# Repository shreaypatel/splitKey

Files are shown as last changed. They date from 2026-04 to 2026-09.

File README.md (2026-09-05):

# Ataraxia - Custom 50% Split Keyboard

### Description
Ataraxia is a wireless 52-key, 3D printed ergonomic keyboard desinged for a focused typing experience. The board is powered by dual Seeed Studio XIAO nRF52840 microcontrollers running ZMK firmware. 
It utilizes Bluetooth 5.0 to communicate seamlessly without a cable connecting the halves. The hardware stack includes a custom-routed printed circuit board, Kailh MX hotswap sockets, and direct-wired 
350mAh LiPo batteries for extended operational life.

This project was designed to create an open source, minimalist workspace that promotes ergonomic health withouting compromising functionality. Beyond the physical utility, it serves as a 
comprehensive hardware engineering exercise. Building this keyboard helped me learn engineering design, CAD modeling, PCB routing, soldering, and embedded firmware compilation. Check out the web app to learn touch typing on this split keyboard layout here: https://ataraxiatype.netlify.app/



3D Model
angle33CAD
angle2CAD
*Full mechanical assembly modeled in Onshape.*

Custom PCB
3dviewbacksdie5
3dviewfrontside
pcbEditorCompleteWiring
*Custom PCB designed and routed in KiCad.*

Wiring Diagram

batteryWiringDiagram
*Simplified direct-wiring diagram connecting the 3.7V LiPo battery to the XIAO nRF52840.*

Bill of Materials (BOM)
[Click here to view the full Bill of Materials (CSV)](<BOM/splitkeyBOM - Sheet1.csv>)

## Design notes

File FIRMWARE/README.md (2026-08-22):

# Firmware (mirror)

This folder mirrors the keyboard definition used to **build** ZMK firmware.

| Repo | Role |
|---|---|
| [zmk-config-ataraxia](https://github.com/shreaypatel/zmk-config-ataraxia) | Source of truth for GitHub Actions builds / flashing |
| `FIRMWARE/` in this repo | Same shield, keymap, and config files for documentation and review |

Keep these in sync when you change pins, matrix transform, or key bindings. Prefer editing [zmk-config-ataraxia](https://github.com/shreaypatel/zmk-config-ataraxia) first, then copy the matching paths here.

### Layout

```
FIRMWARE/
  build.yaml
  config/
    ataraxia.conf
    ataraxia.keymap
    west.yml
    boards/shields/ataraxia/
      ataraxia.dtsi
      ataraxia_left.overlay
      ataraxia_right.overlay
      Kconfig.defconfig
      Kconfig.shield
      ataraxia.zmk.yml
  zephyr/
    module.yml
```

ZMK does not use a project `main.c` for this board — hardware and keymap live in the DeviceTree overlays / `.dtsi` and `.keymap` files above.

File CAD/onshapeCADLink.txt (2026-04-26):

https://cad.onshape.com/documents/b6f8556d38045e68e5a1e84c/w/d274bab0f518b6b404911204/e/6b84c119cb265b001b29e227

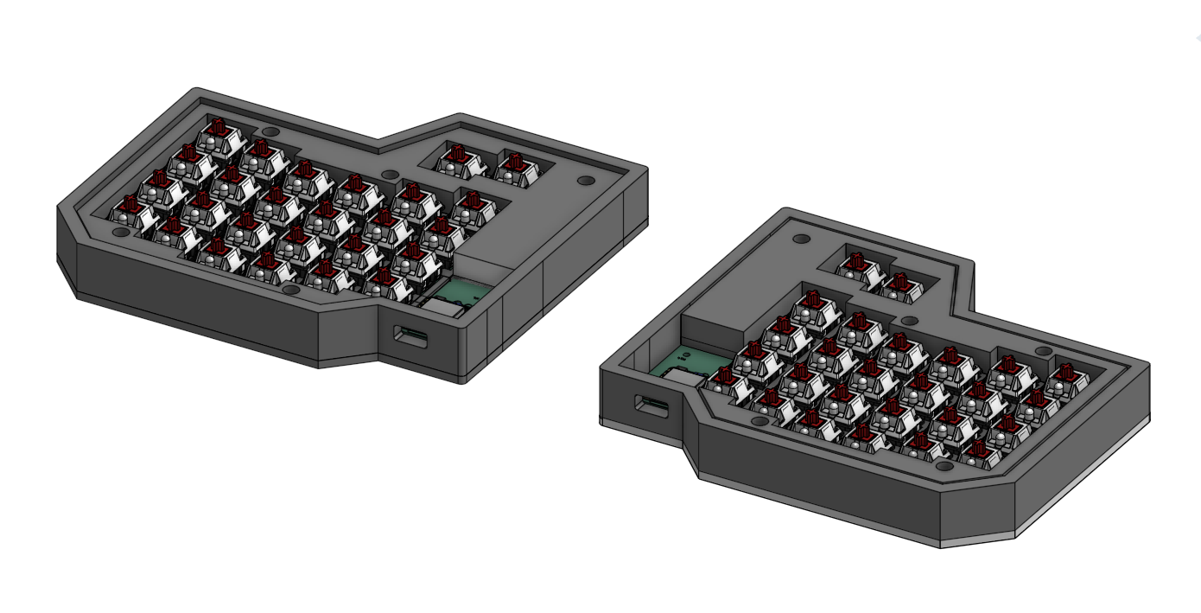
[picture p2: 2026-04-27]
CAD/angle2CAD.png

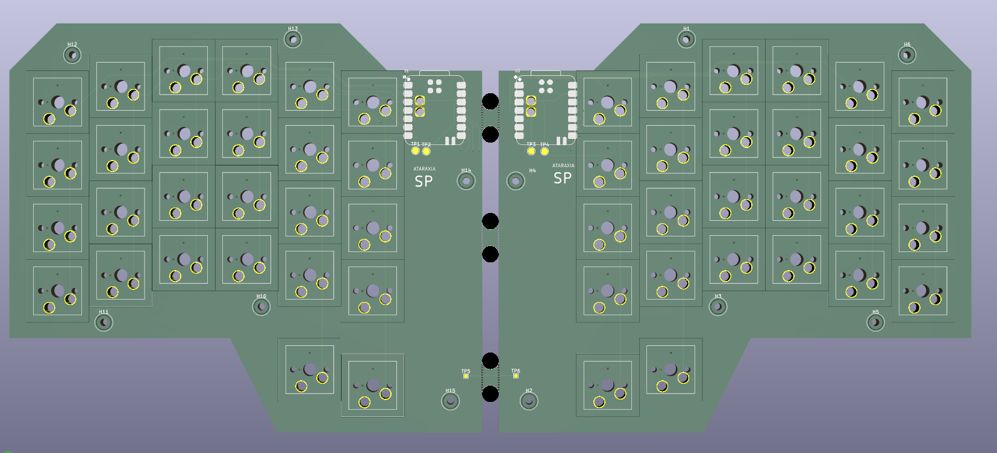
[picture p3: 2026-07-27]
PCB/3dviewfrontside.png

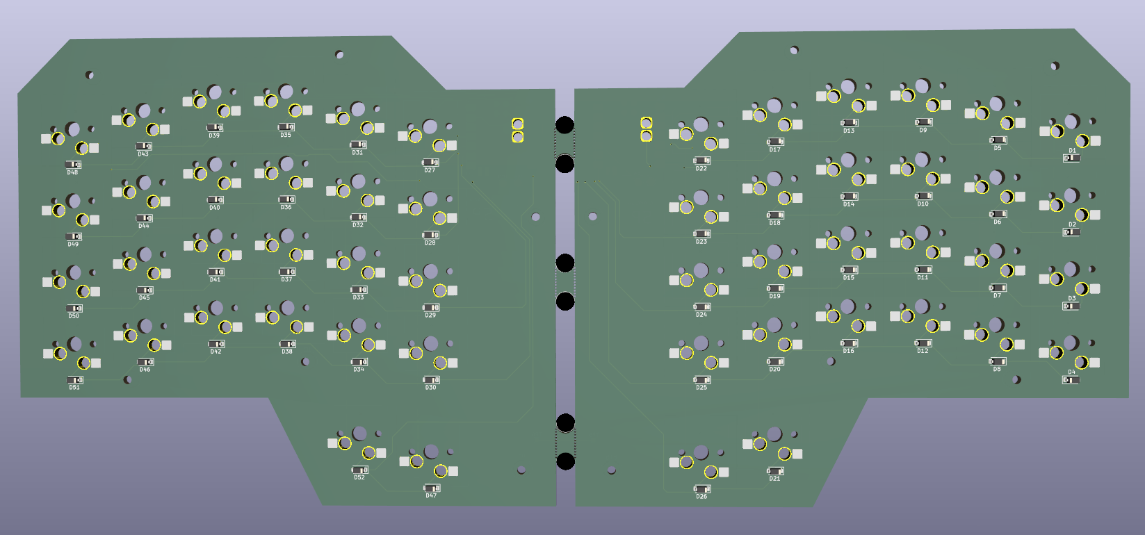
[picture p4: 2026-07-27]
PCB/3dviewbacksdie5.png

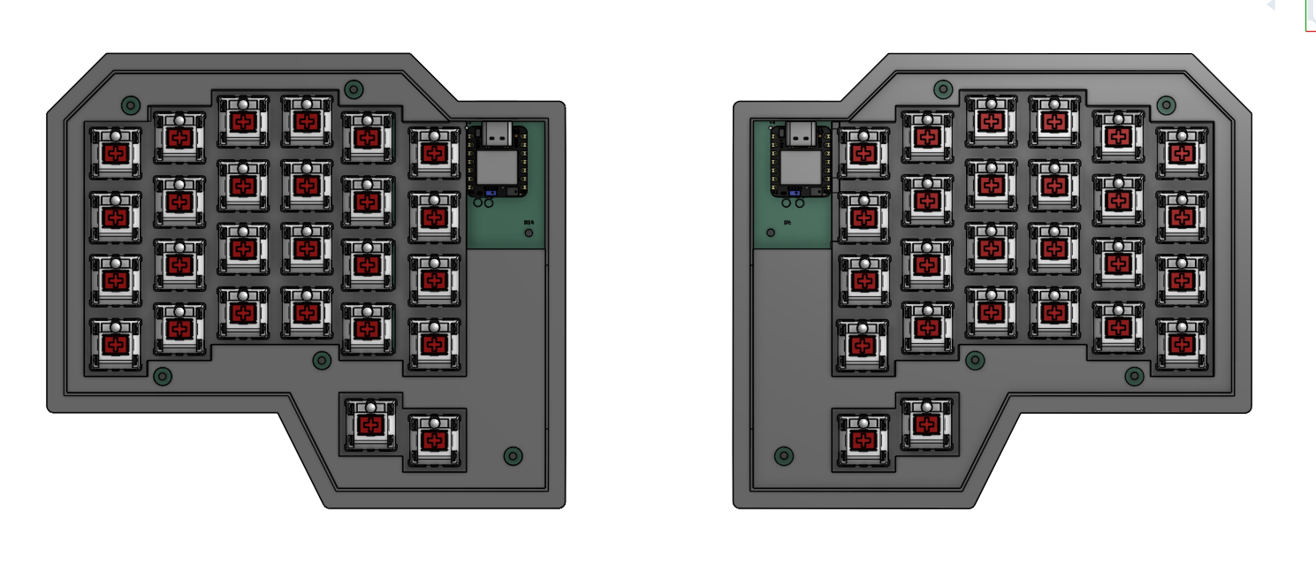
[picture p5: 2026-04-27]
CAD/angle3CAD.png

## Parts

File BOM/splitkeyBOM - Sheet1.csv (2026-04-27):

Part | Price (USD) | Quantity | Total Cost Inlcuding Shipping(USD) | Website
Lipo Battery 3.7 V | 4.95 | 2 | 8.12 | https://www.aliexpress.com/item/33007984508.html?src=google
PCB | 18.5 | 5 | 28.04 | https://cart.jlcpcb.com/shopcart/cart/
MX Switches | 0.09875 | 80 | 7.90 | https://www.aliexpress.com/item/1005011838889689.html?scm_id=1007.40050.354490.0&scm-url=1007.40050.354490.0
PBT Keycaps | 0.2572 | 25 | 6.43 | https://www.aliexpress.com/item/32842379355.html?mp=1
XIAO nRF52840 | 10.69 | 2 | 21.38 | https://www.aliexpress.com/item/1005006988954136.html?scm_id=1007.13440.426876.0&scm-url=1007.13440.426876.0
1N5819 Diodes | 0.0322 | 100 | 3.22 | https://www.aliexpress.com/item/1005010373909049.html?curPageLogUid=VT8pOmptmrYM
Hot-Swap PCB Socket | 0.09542857143 | 70 | 6.68 | https://www.aliexpress.com/item/1005007225352311.html?scm_id=1007.40050.354490.0&scm-url=1007.40050.354490.0
M2 threaded brass inserts | 0.0458 | 50 | 2.29 | https://www.aliexpress.com/item/1005008666672949.html?curPageLogUid=kukGMW7BGeht
M2 Screws 4mm length | 0.0286 | 50 | 1.43 | https://www.aliexpress.com/item/32967225441.html?curPageLogUid=wkBiljUuE5jX
3D printed case |  | 1 | 0.00 | printing at home
 |  |  | 85.49

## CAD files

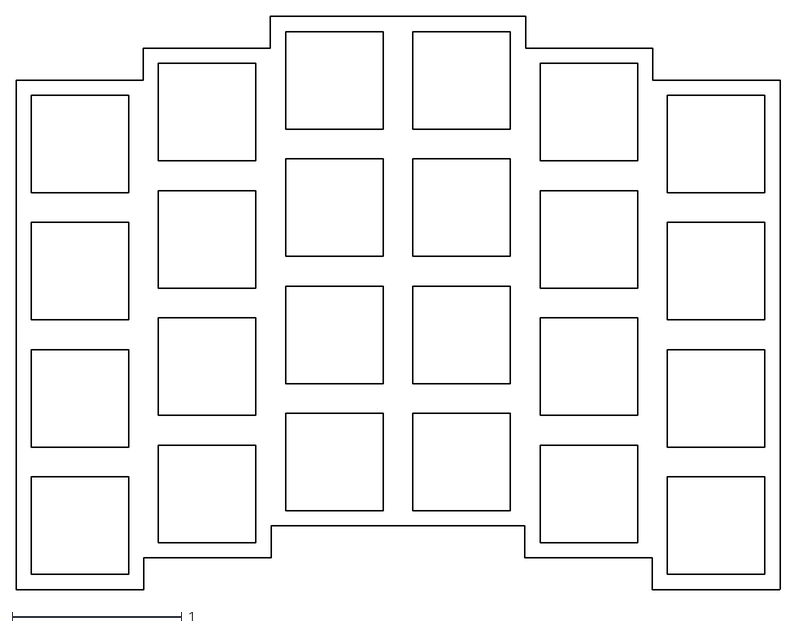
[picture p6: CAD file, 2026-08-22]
web/rightkeyoutlinemain.dxf
4.50 x 3.38

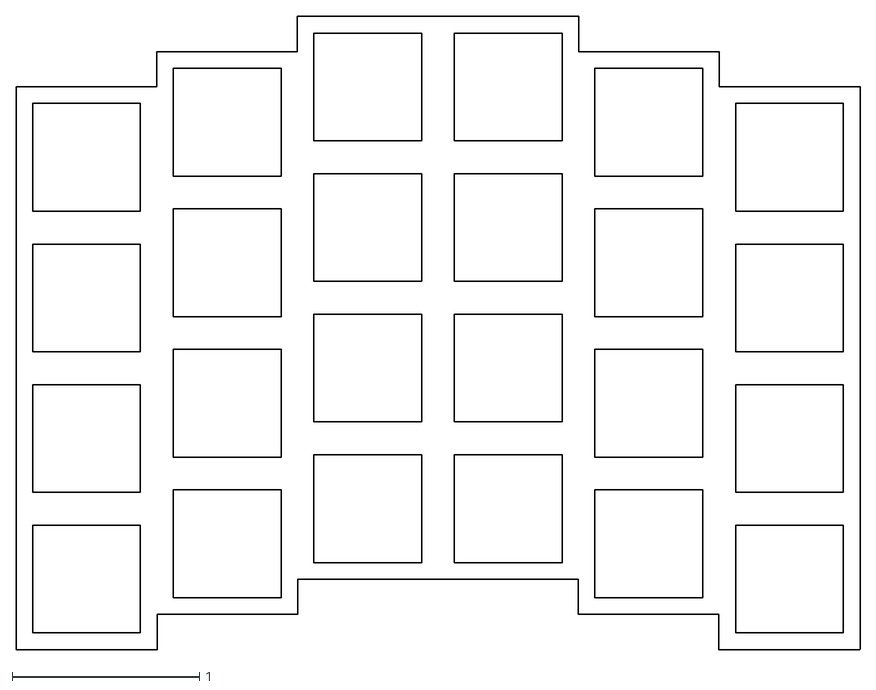
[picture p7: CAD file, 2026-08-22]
web/leftKeyOutlineMain.dxf
4.50 x 3.38

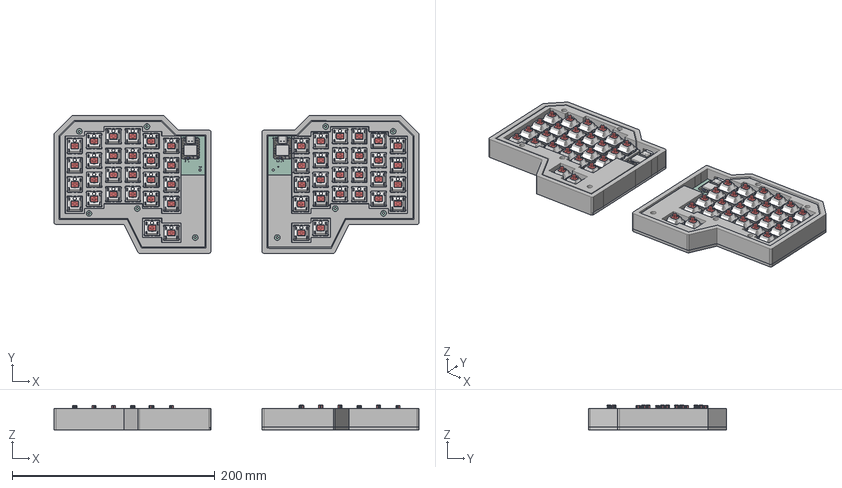
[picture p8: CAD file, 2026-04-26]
CAD/splitKeyElectronics.step
360.1 x 135.9 x 24.6 mm
splitKey_silkscreen x 249
Pieza5^Cherry MX x 52
Pulsador x 52
Pin1 x 52
Led 3mm_trans x 104
BOSS-EXTRUDE14_10_ x 2
PCB (1) x 32
CAP 3 x 6
Pin2 x 52
Bottom x 52
BOSS-EXTRUDE7_7_ x 2
Pins x 8
MIRROR2 x 2
Top x 52
MSM261D3526H1CPM x 16
LED x 8
BOSS-EXTRUDE14_12_ x 2
BOSS-EXTRUDE7_9_ x 2
Silkscreen x 26
CAP x 12
BOSS-EXTRUDE14_9_ x 2
ANT1 x 6
Surface 250
BOSS-EXTRUDE14_8_ x 2
BOSS-EXTRUDE7_4_ x 2
splitKey_PCB_2
BOSS-EXTRUDE14_2_ x 2
CUT-EXTRUDE5 x 2
Shield x 2
BOSS-EXTRUDE14_7_ x 2
BOSS-EXTRUDE7_2_ x 2
BOSS-EXTRUDE14_1_ x 2
BOSS-EXTRUDE14_11_ x 2
BOSS-EXTRUDE7_1_ x 2
BOSS-EXTRUDE14_5_ x 2
BOSS-EXTRUDE7_3_ x 2
BOSS-EXTRUDE14_6_ x 2
BOSS-EXTRUDE7_5_ x 2
BOSS-EXTRUDE7_8_ x 2
USR x 2
BOSS-EXTRUDE7_6_ x 2
splitKey_PCB_1
BOSS-EXTRUDE14_4_ x 2
BOSS-EXTRUDE14_3_ x 2

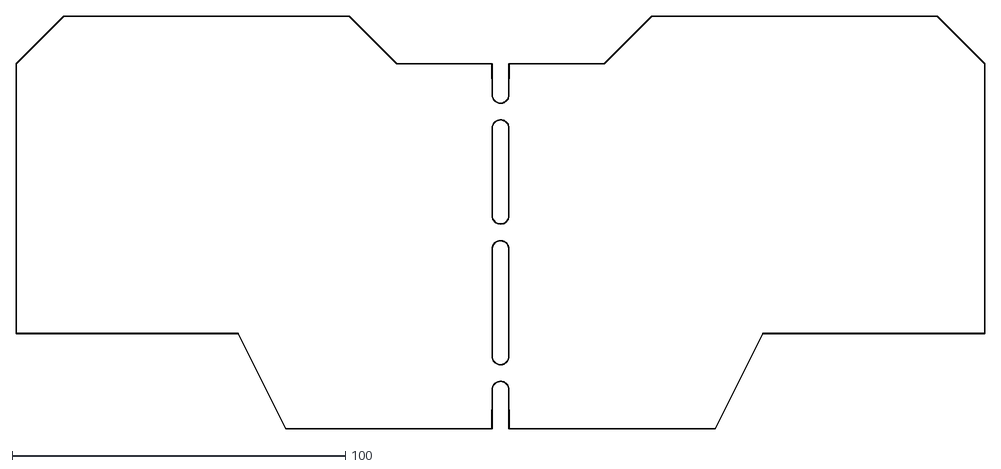
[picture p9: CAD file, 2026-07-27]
PCB/sourceFiles/splitKey-Edge_Cuts.dxf
290.9 x 123.9

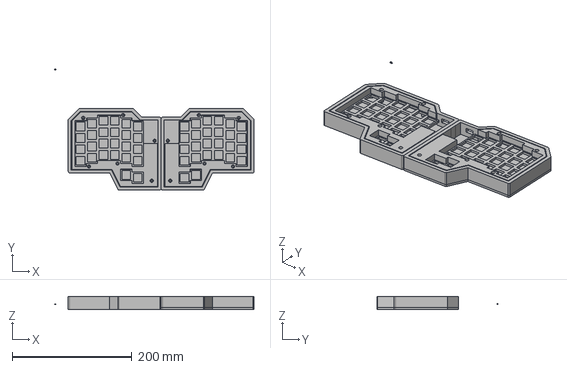
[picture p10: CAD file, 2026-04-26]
CAD/splitKeyCaseEnclosure.step
333.9 x 202.1 x 21.0 mm

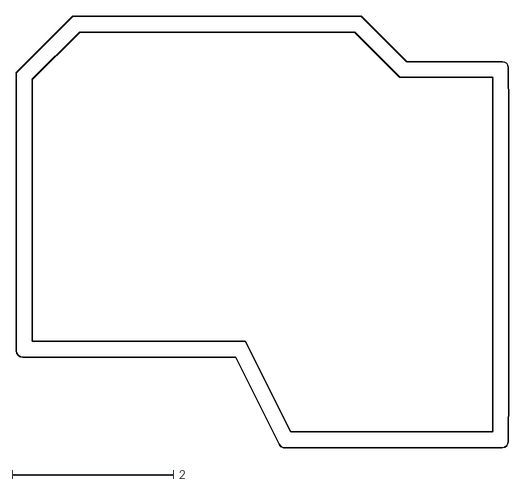
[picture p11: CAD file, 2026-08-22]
web/left outline.dxf
6.10 x 5.35

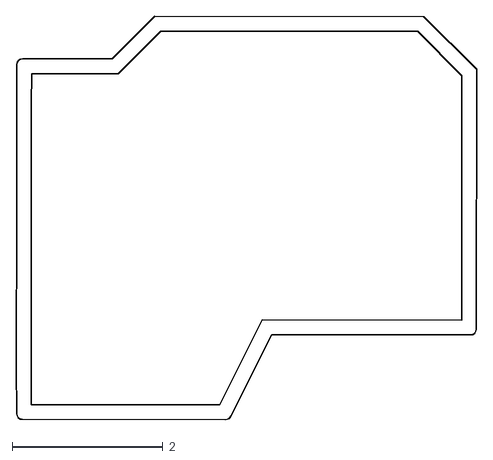
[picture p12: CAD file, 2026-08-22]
web/rightOUtline.dxf
6.10 x 5.35

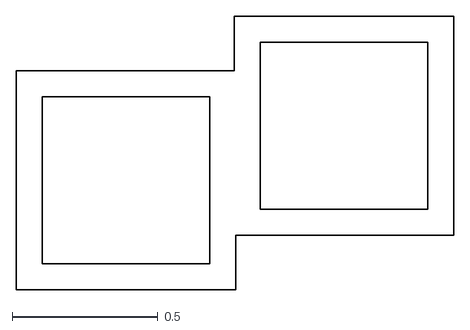
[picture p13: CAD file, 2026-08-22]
web/rightkeyoutlinethumbcluster.dxf
1.50 x 0.941

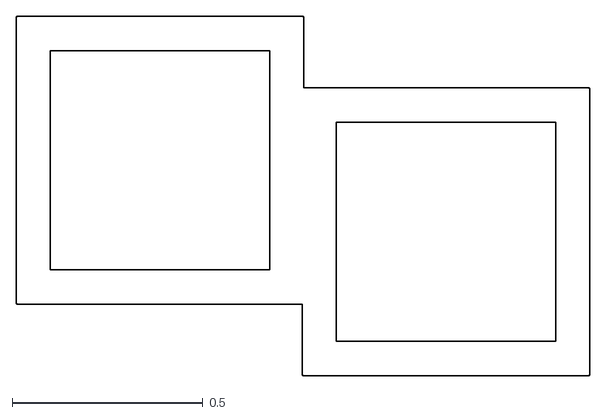
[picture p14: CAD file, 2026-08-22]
web/leftkeyOutlineThumbCluster.dxf
1.50 x 0.941

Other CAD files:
PCB/sourceFiles/splitKey-F_Silkscreen.dxf

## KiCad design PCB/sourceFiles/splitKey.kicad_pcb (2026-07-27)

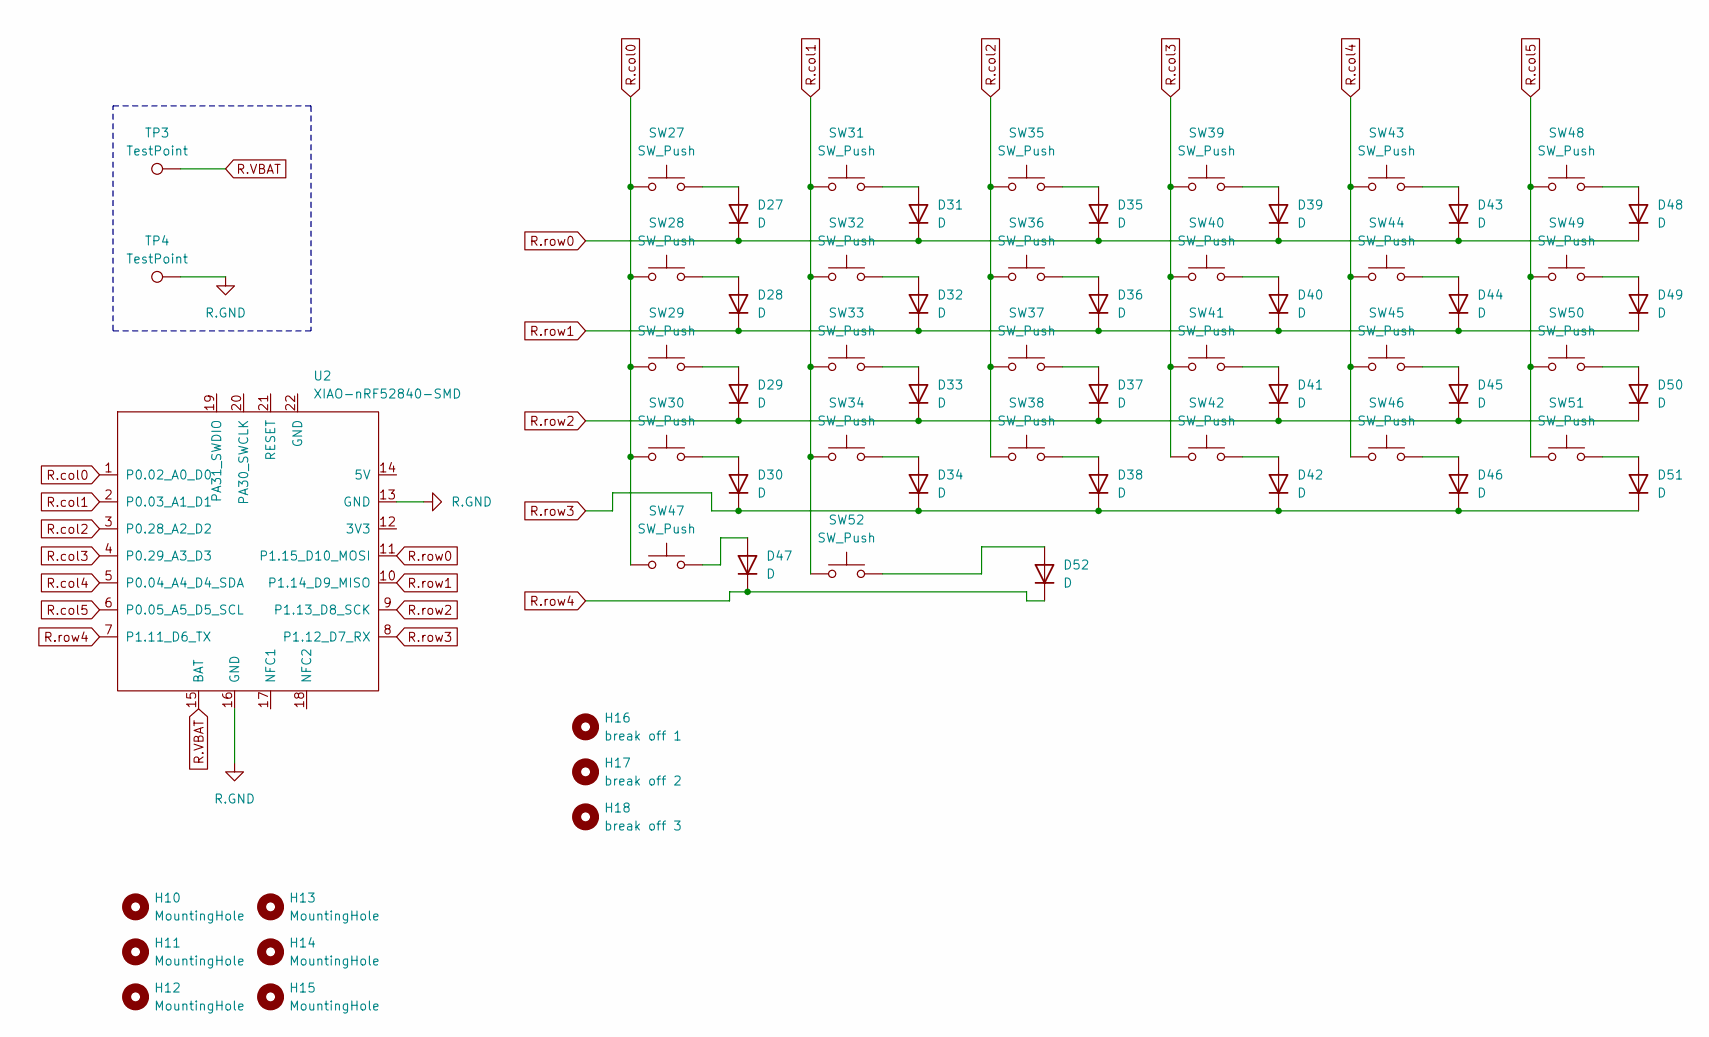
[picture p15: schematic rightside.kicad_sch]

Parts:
D27, D28, D29, D30, D31, D32, D33, D34, D35, D36, D37, D38, D39, D40, D41, D42, D43, D44, D45, D46, D47, D48, D49, D50, D51, D52: D; D_SOD-123
H10, H11, H12, H13, H14, H15: MountingHole; MountingHole_2.2mm_M2
H16: break off 1; mouse-bite-5mm-slot
H17: break off 2; mouse-bite-5mm-slot
H18: break off 3; mouse-bite-5mm-slot
SW27, SW28, SW29, SW30, SW31, SW32, SW33, SW34, SW35, SW36, SW37, SW38, SW39, SW40, SW41, SW42, SW43, SW44, SW45, SW46, SW47, SW48, SW49, SW50, SW51, SW52: SW_Push; MX_Hotswap_1.00u
TP3, TP4: TestPoint; TestPoint_Pad_D2.0mm
U2: XIAO-nRF52840-SMD; modified-XIAO-nRF52840-SMD

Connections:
unnamed: D27.2 (A), SW27.2
unnamed: D28.2 (A), SW28.2
unnamed: D29.2 (A), SW29.2
unnamed: D30.2 (A), SW30.2
unnamed: D31.2 (A), SW31.2
unnamed: D32.2 (A), SW32.2
unnamed: D33.2 (A), SW33.2
unnamed: D34.2 (A), SW34.2
unnamed: D35.2 (A), SW35.2
unnamed: D36.2 (A), SW36.2
unnamed: D37.2 (A), SW37.2
unnamed: D38.2 (A), SW38.2
unnamed: D39.2 (A), SW39.2
unnamed: D40.2 (A), SW40.2
unnamed: D41.2 (A), SW41.2
unnamed: D42.2 (A), SW42.2
unnamed: D43.2 (A), SW43.2
unnamed: D44.2 (A), SW44.2
unnamed: D45.2 (A), SW45.2
unnamed: D46.2 (A), SW46.2
unnamed: D47.2 (A), SW47.2
unnamed: D48.2 (A), SW48.2
unnamed: D49.2 (A), SW49.2
unnamed: D50.2 (A), SW50.2
unnamed: D51.2 (A), SW51.2
unnamed: D52.2 (A), SW52.2
R.GND: TP4.1 (1_1), U2.13 (GND), U2.16 (GND)
R.VBAT: TP3.1 (1_1), U2.15 (BAT)
R.col0: SW27.1, SW28.1, SW29.1, SW30.1, SW47.1, U2.1 (P0.02_A0_D0)
R.col1: SW31.1, SW32.1, SW33.1, SW34.1, SW52.1, U2.2 (P0.03_A1_D1)
R.col2: SW35.1, SW36.1, SW37.1, SW38.1, U2.3 (P0.28_A2_D2)
R.col3: SW39.1, SW40.1, SW41.1, SW42.1, U2.4 (P0.29_A3_D3)
R.col4: SW43.1, SW44.1, SW45.1, SW46.1, U2.5 (P0.04_A4_D4_SDA)
R.col5: SW48.1, SW49.1, SW50.1, SW51.1, U2.6 (P0.05_A5_D5_SCL)
R.row0: D27.1 (K), D31.1 (K), D35.1 (K), D39.1 (K), D43.1 (K), D48.1 (K), U2.11 (P1.15_D10_MOSI)
R.row1: D28.1 (K), D32.1 (K), D36.1 (K), D40.1 (K), D44.1 (K), D49.1 (K), U2.10 (P1.14_D9_MISO)
R.row2: D29.1 (K), D33.1 (K), D37.1 (K), D41.1 (K), D45.1 (K), D50.1 (K), U2.9 (P1.13_D8_SCK)
R.row3: D30.1 (K), D34.1 (K), D38.1 (K), D42.1 (K), D46.1 (K), D51.1 (K), U2.8 (P1.12_D7_RX)
R.row4: D47.1 (K), D52.1 (K), U2.7 (P1.11_D6_TX)

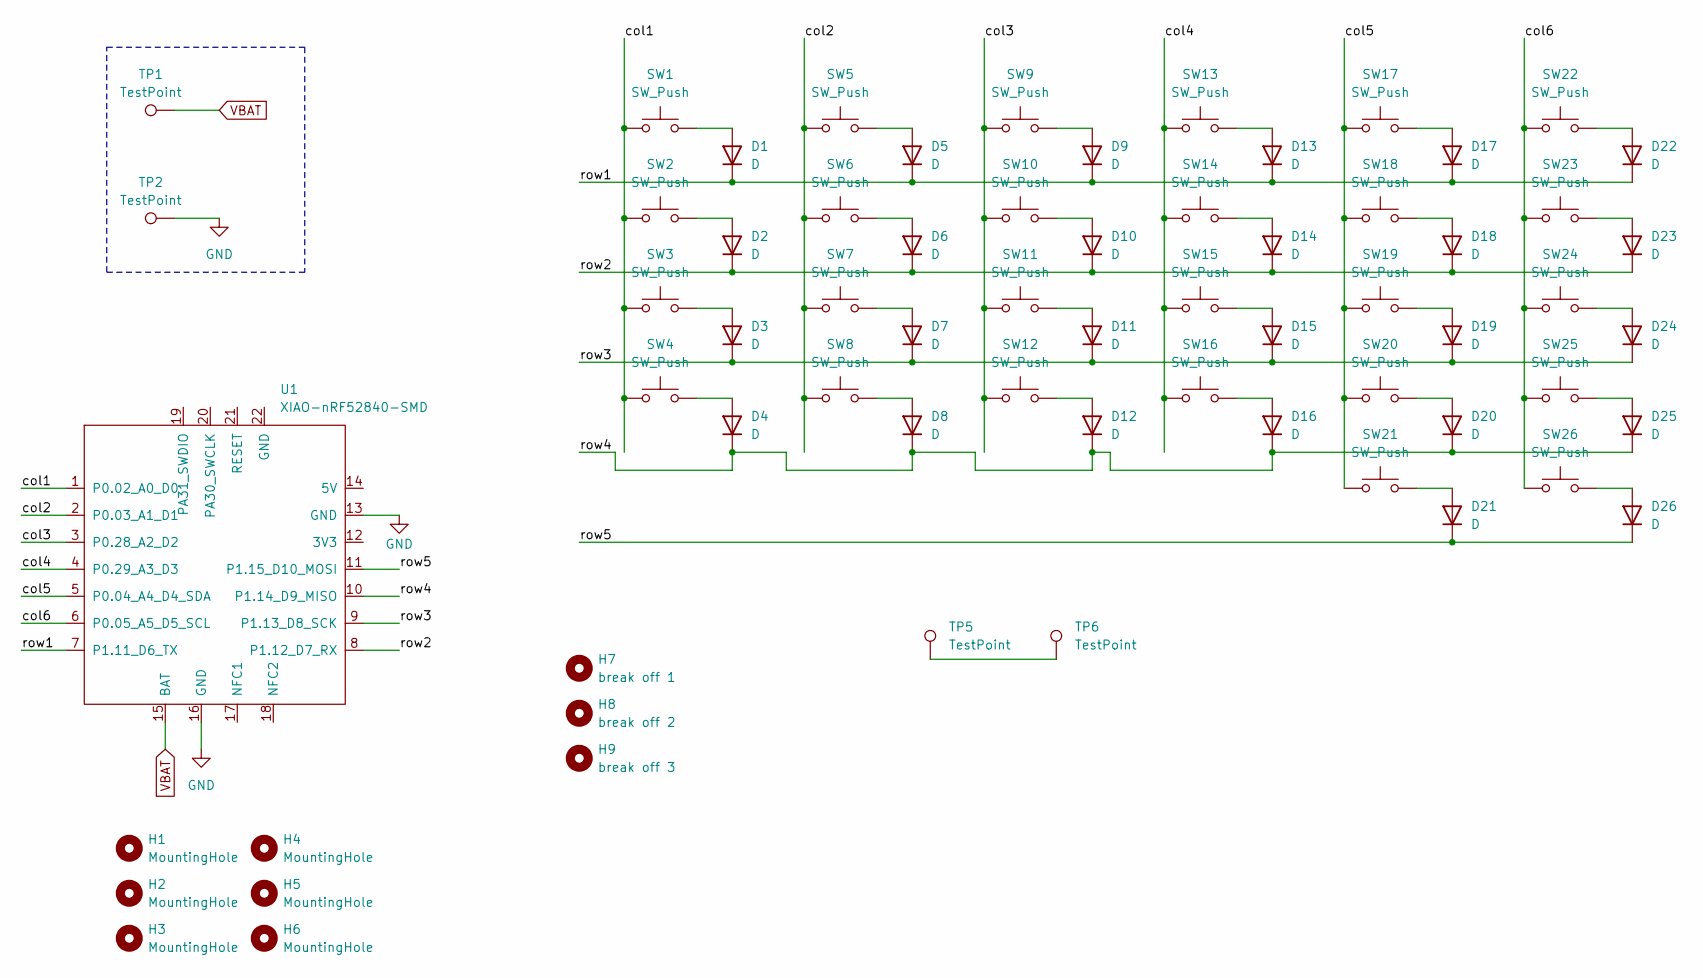
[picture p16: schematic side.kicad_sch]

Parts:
D1, D2, D3, D4, D5, D6, D7, D8, D9, D10, D11, D12, D13, D14, D15, D16, D17, D18, D19, D20, D21, D22, D23, D24, D25, D26: D; D_SOD-123
H1, H2, H3, H4, H5, H6: MountingHole; MountingHole_2.2mm_M2
H7: break off 1; mouse-bite-5mm-slot
H8: break off 2; mouse-bite-5mm-slot
H9: break off 3; mouse-bite-5mm-slot
SW1, SW2, SW3, SW4, SW5, SW6, SW7, SW8, SW9, SW10, SW11, SW12, SW13, SW14, SW15, SW16, SW17, SW18, SW19, SW20, SW21, SW22, SW23, SW24, SW25, SW26: SW_Push; MX_Hotswap_1.00u
TP1, TP2: TestPoint; TestPoint_Pad_D2.0mm
TP5, TP6: TestPoint; TestPoint_Pad_1.0x1.0mm
U1: XIAO-nRF52840-SMD; modified-XIAO-nRF52840-SMD

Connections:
/left/col1: SW1.1, SW2.1, SW3.1, SW4.1, U1.1 (P0.02_A0_D0)
/left/col2: SW5.1, SW6.1, SW7.1, SW8.1, U1.2 (P0.03_A1_D1)
/left/col3: SW9.1, SW10.1, SW11.1, SW12.1, U1.3 (P0.28_A2_D2)
/left/col4: SW13.1, SW14.1, SW15.1, SW16.1, U1.4 (P0.29_A3_D3)
/left/col5: SW17.1, SW18.1, SW19.1, SW20.1, SW21.1, U1.5 (P0.04_A4_D4_SDA)
/left/col6: SW22.1, SW23.1, SW24.1, SW25.1, SW26.1, U1.6 (P0.05_A5_D5_SCL)
/left/row1: D1.1 (K), D5.1 (K), D9.1 (K), D13.1 (K), D17.1 (K), D22.1 (K), U1.7 (P1.11_D6_TX)
/left/row2: D2.1 (K), D6.1 (K), D10.1 (K), D14.1 (K), D18.1 (K), D23.1 (K), U1.8 (P1.12_D7_RX)
/left/row3: D3.1 (K), D7.1 (K), D11.1 (K), D15.1 (K), D19.1 (K), D24.1 (K), U1.9 (P1.13_D8_SCK)
/left/row4: D4.1 (K), D8.1 (K), D12.1 (K), D16.1 (K), D20.1 (K), D25.1 (K), U1.10 (P1.14_D9_MISO)
/left/row5: D21.1 (K), D26.1 (K), U1.11 (P1.15_D10_MOSI)
GND: TP2.1 (1_1), U1.13 (GND), U1.16 (GND)
unnamed: D1.2 (A), SW1.2
unnamed: D2.2 (A), SW2.2
unnamed: D3.2 (A), SW3.2
unnamed: D4.2 (A), SW4.2
unnamed: D5.2 (A), SW5.2
unnamed: D6.2 (A), SW6.2
unnamed: D7.2 (A), SW7.2
unnamed: D8.2 (A), SW8.2
unnamed: D9.2 (A), SW9.2
unnamed: D10.2 (A), SW10.2
unnamed: D11.2 (A), SW11.2
unnamed: D12.2 (A), SW12.2
unnamed: D13.2 (A), SW13.2
unnamed: D14.2 (A), SW14.2
unnamed: D15.2 (A), SW15.2
unnamed: D16.2 (A), SW16.2
unnamed: D17.2 (A), SW17.2
unnamed: D18.2 (A), SW18.2
unnamed: D19.2 (A), SW19.2
unnamed: D20.2 (A), SW20.2
unnamed: D21.2 (A), SW21.2
unnamed: D22.2 (A), SW22.2
unnamed: D23.2 (A), SW23.2
unnamed: D24.2 (A), SW24.2
unnamed: D25.2 (A), SW25.2
unnamed: D26.2 (A), SW26.2
unnamed: TP5.1 (1_1), TP6.1 (1_1)
VBAT: TP1.1 (1_1), U1.15 (BAT)

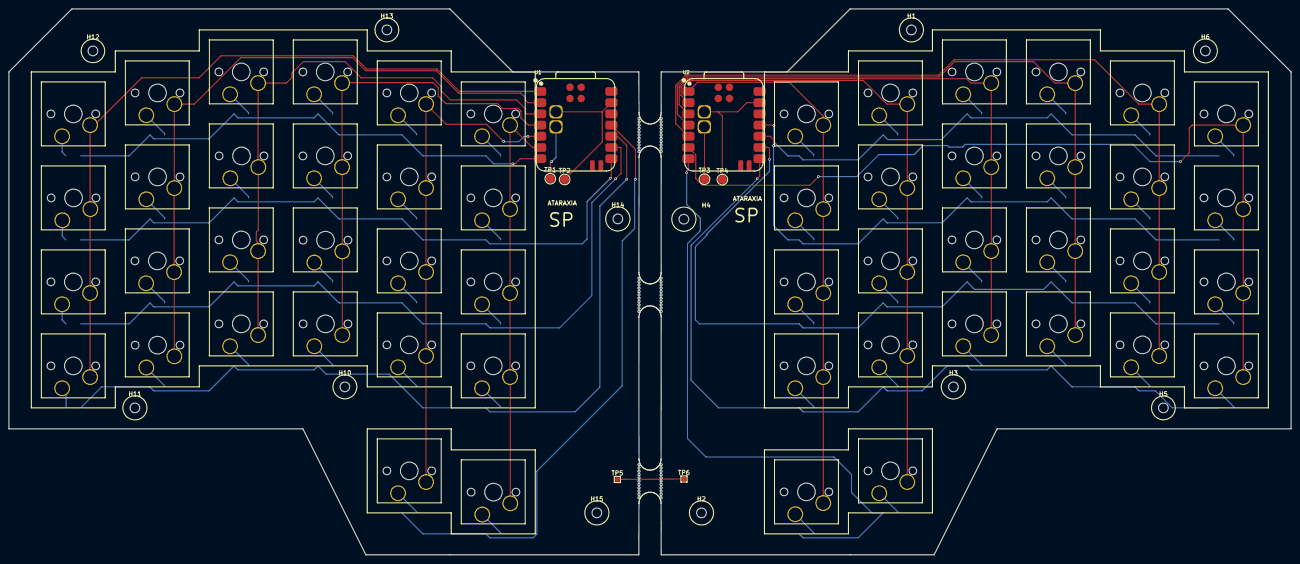
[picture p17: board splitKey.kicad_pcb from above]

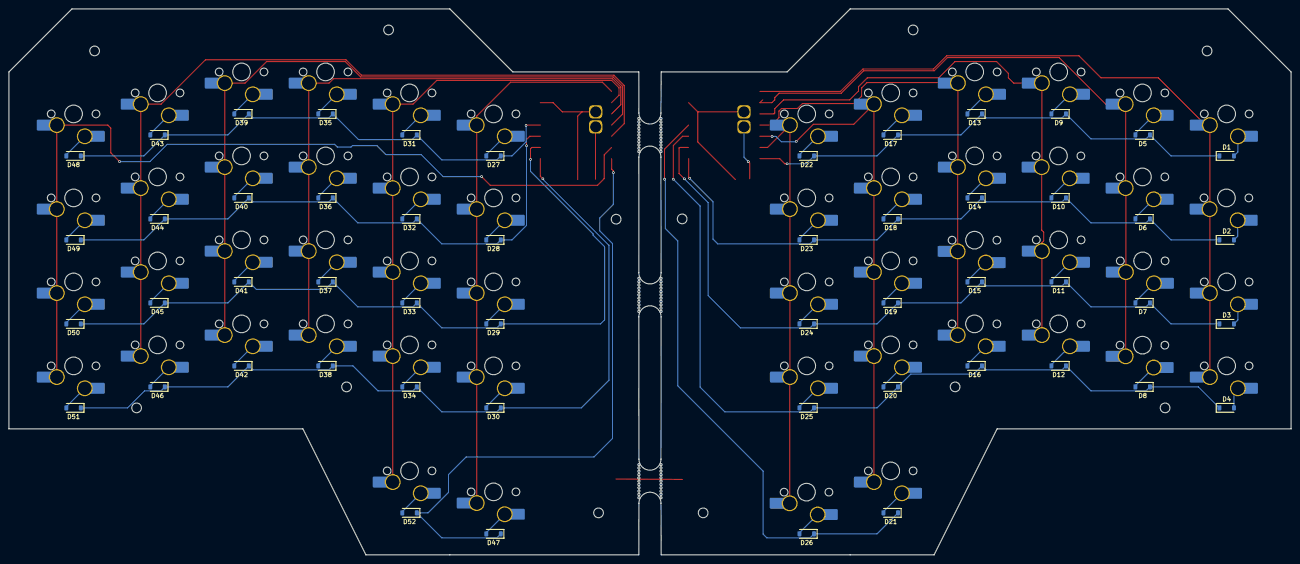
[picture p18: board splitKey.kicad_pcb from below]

Board: 2 copper layers, 290.8 x 123.8 mm, 127 parts (104 on the bottom side), 79 nets.

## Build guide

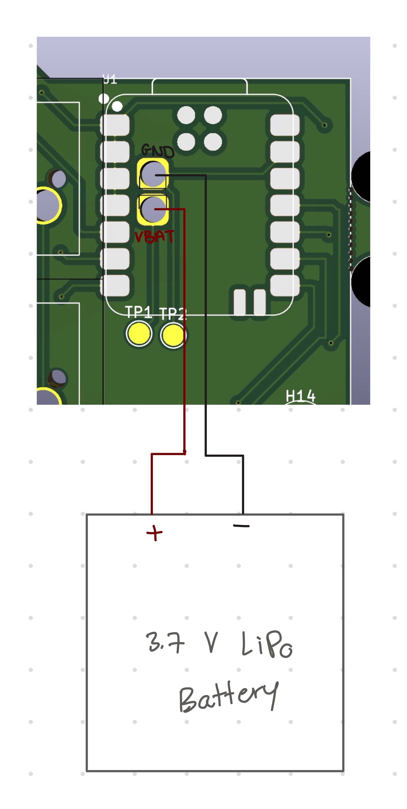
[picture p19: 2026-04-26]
PCB/batteryWiringDiagram.jpg

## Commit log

2026-04-26 iniital commit for Ataraxia split keyboard
    [splitKey-B_Cu.gbl, splitKey-B_Mask.gbs, splitKey-B_Paste.gbp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]
2026-04-27 upadated BOM
    [splitkeyBOM - Sheet1.csv]
2026-04-27 Create README for Ataraxia keyboard project
    Added detailed project description, images, and BOM.
2026-04-27 updated files
    [splitKey.kicad_pcb, splitKey.kicad_sch]
2026-05-01 added misisng hierarchal files
    [rightside.kicad_sch, side.kicad_sch]
2026-07-27 updated PCB from KiCad sourcs and gerbers
    [rightside.kicad_sch, side.kicad_sch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]
2026-07-27 Update README with new images and PCB details
    Added new images and updated descriptions for the 3D model and custom PCB sections.
2026-08-22 Add Ataraxia web tutor and Netlify config.
    [left outline.dxf, leftKeyOutlineMain.dxf, leftkeyOutlineThumbCluster.dxf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]
2026-09-05 Update README with wiring diagram and BOM section
